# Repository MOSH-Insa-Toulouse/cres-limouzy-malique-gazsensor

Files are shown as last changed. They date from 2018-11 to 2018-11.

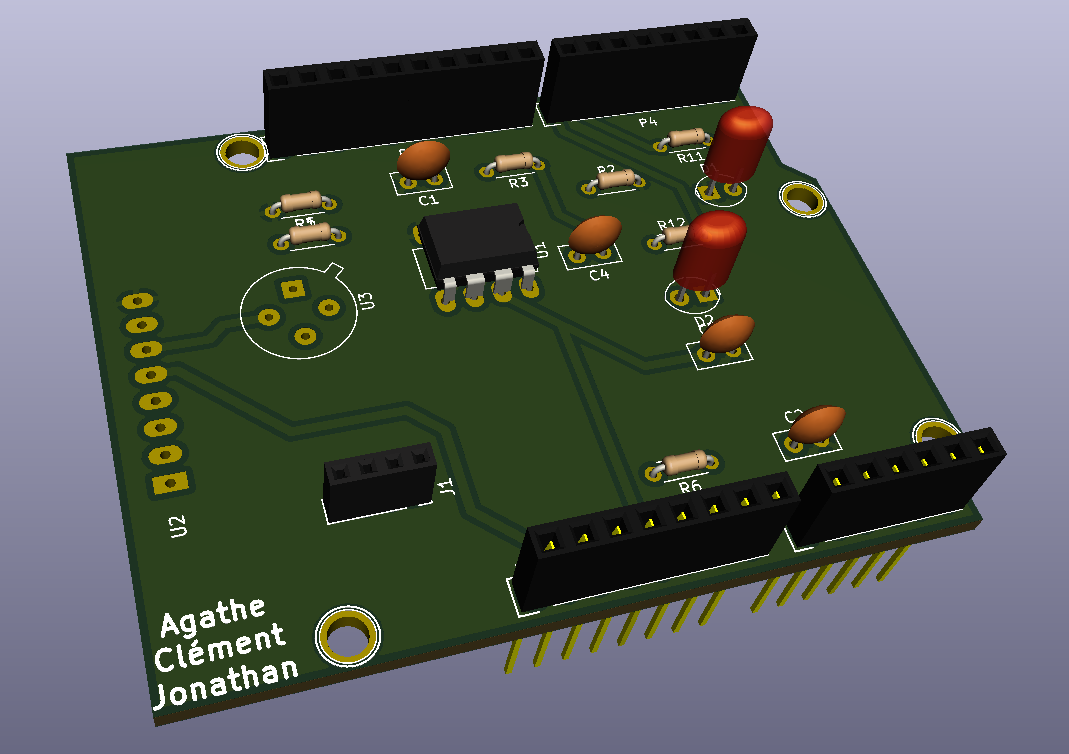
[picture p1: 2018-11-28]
images/3D.PNG

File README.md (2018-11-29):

# Capteur intelligent de gaz monté sur une Arduino Uno
Dans le cadre du cours "Microcontrolleurs et open-source hardware" de 5ème année ISS (Innovative Smart System) à l'INSA de Toulouse, nous avons réalisé un shield Arduino incluant une carte Lora afin de faire transiter les informations issues de divers capteurs sur ledit réseau bas débit. Le projet se décompose en plusieurs parties :
* Création du shield Arduino Uno sous KiCad incluant :
  - la puce Lora RN2483 et son antenne associée
  - le capteur de gaz MQ2 avec connectique GROVE
  - un capteur de gaz "maison" et son étage d'amplification
  - deux LEDs
* Développement d'un programme sous l'IDE Arduino permettant de récupérer les informations issues de divers capteurs branchés sur l'Arduino et les transmettre sur le réseau basse consommation Lora nommé TheThingsNetwork.
* Création d'une interface web affichant les informations issues du capteur de gaz sous la forme d'un graphe, grâce à node-red.

# Prérequis
* Software
	- Arduino IDE avec les bibliothéques SoftwareSerial et TheThingsNetwork
	- Un compte TheThingsNetwork
	- Node-red
* Hardware
	- Un Arduino Uno
	- Un capteur de gaz MQ2 avec connecteur GROVE
	- Deux LEDs
	- Une puce Lora RN2483

# Création d'un shield pour Arduino Uno
Vous pouvez trouver les sources KiCad dans le dossier [ShieldArduinoKiCad](/ShieldArduinoKicad/).
Vous trouverez ci-dessous une vue d'ensemble de la schématique, du routage et du rendu 3D de notre shield.
Schématique du shield Arduino
Routage du shield Arduino - Face 1
Routage du shield Arduino - Face 2
Rendu 3D du shield Arduino

# Développement du software sur Arduino Uno
Le code est distribué dans le dossier [arduino](/arduino/).
Concrétement, il implémente :
* La connexion de la carte Lora au réseau TheThingsNetwork
* La mise en place d'un mode uplink (communication Arduino --> theThingsNetwork via Lora afin d'envoyer les informations issues des capteurs)
* La mise en place d'un mode downlink (communication theThingsNetwork --> Arduino via Lora permettant de commander des LEDs via une interface web). Il est intéressant de noter que la réception d'un message sur l'arduino (message downlink) se fait uniquement après l'envoi d'un message uplink, car la puce RN2483 est un device Lora de classe A. C'est pourquoi il est obligatoire d'envoyer périodiquement une trame (manuellement à l'aide d'un *sendBytes* ou automatiquement à l'aide de la fonction *ttn.poll()*)
* La mise en place de deux LEDs, l'une indiquant un niveau de gaz trop élevé dans la pièce, l'autre permettant de tester le mode downlink

# Développement d'une interface graphique de gestion de données grâce à node-red
Node-red est un outil graphique permettant de lier plusieurs services et APIs ensemble de manière assez facile. Ainsi, nous avons créé une interface permettant d'afficher les informations issues du capteur de gaz sous forme de gauge de danger. De plus, nous avons la possibilité d'allumer, d'éteindre ou de faire clignoter la LED sur notre Arduino, à distance grâce à node-red ou l'interface theThingsNetwork. Vous trouverez ci-dessous l'interface node-red créé pour le projet ainsi que le rendu graphique final.
Interface de programmation de node-red
Rendu graphique final

# FAQ software
## La connexion à TheThingsNetwork ne fonctionne pas
* Réinitialiser l'Arduino à l'aide du bouton RESET, ainsi que la carte Lora en branchant la pin RST du RN2483 sur la masse de l'arduino pendant quelques secondes
* Vérifier qu'une gateway Lora est bien présente aux alentours et que le signal est suffisamment fort pour permettre la connexion

## La connexion de node-red à TheThingsNetwork est impossible
* Vérifier que votre routeur internet ne bloque pas la connexion

## Le mode uplink ne fonctionne pas
* Vérifier que la connexion avec TheThingsNetwork est bien réalisée à l'aide de la console série Arduino
* Cliquer sur "RESET FRAME COUNTERS" sur la page de votre device sur TheThingsNetwork

## Le mode downlink ne fonctionne pas
* Vérifier que la connexion avec TheThingsNetwork est bien réalisée à l'aide de la console série Arduino
* Vérifier que votre code envoie périodiquement des trames Lora afin de permettre les messages downlink

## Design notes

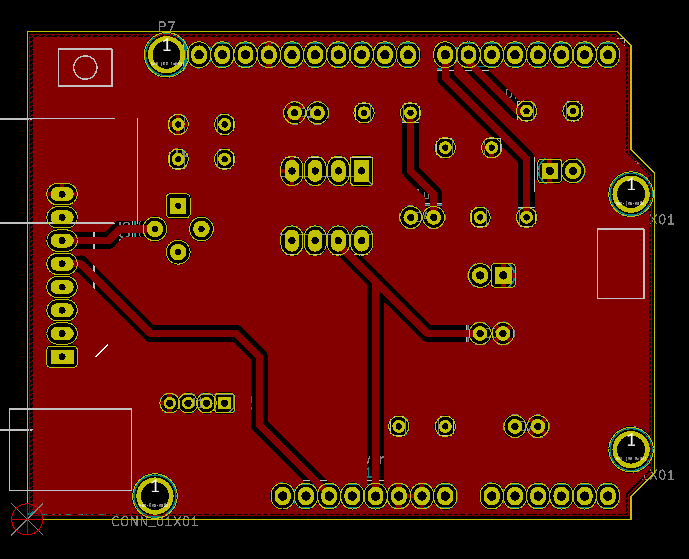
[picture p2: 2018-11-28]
images/routageB.PNG

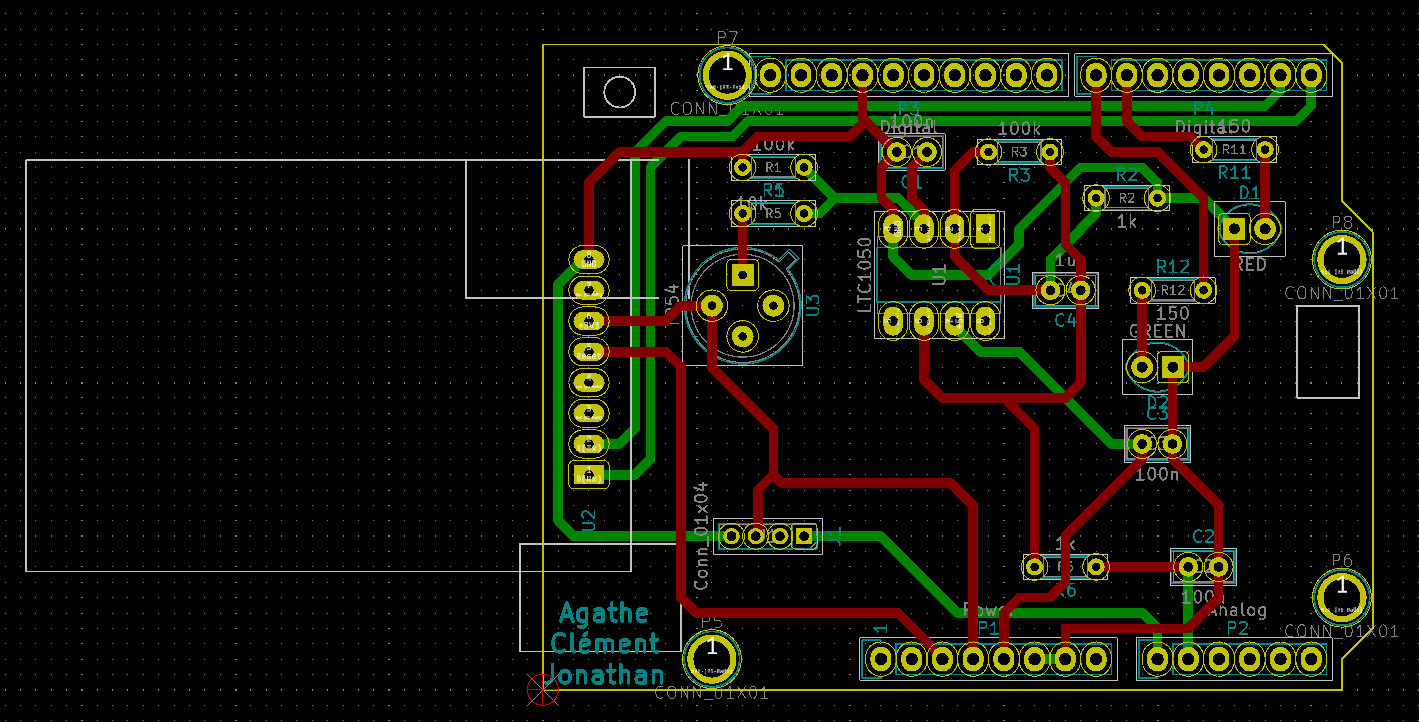
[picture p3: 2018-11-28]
images/routage.PNG

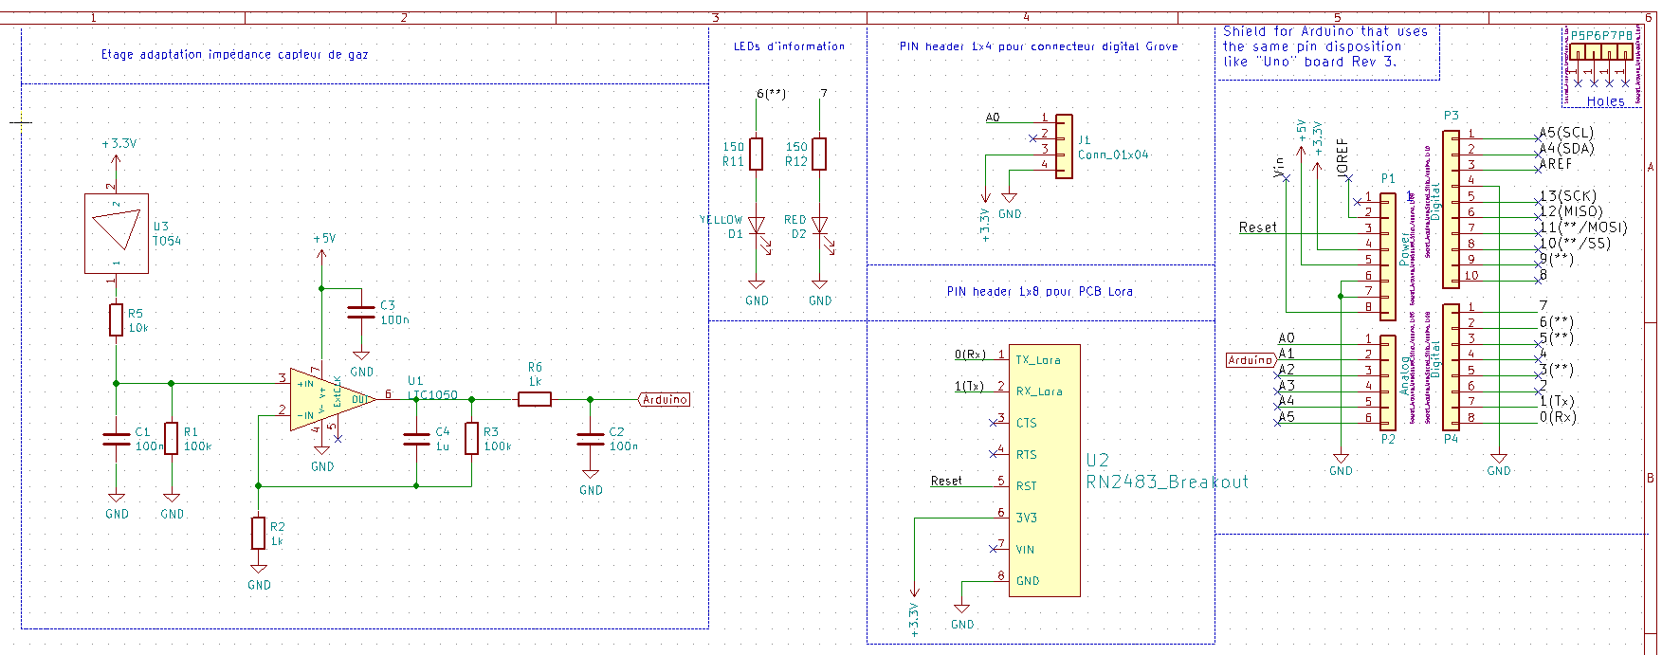
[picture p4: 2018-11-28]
images/schematique.PNG

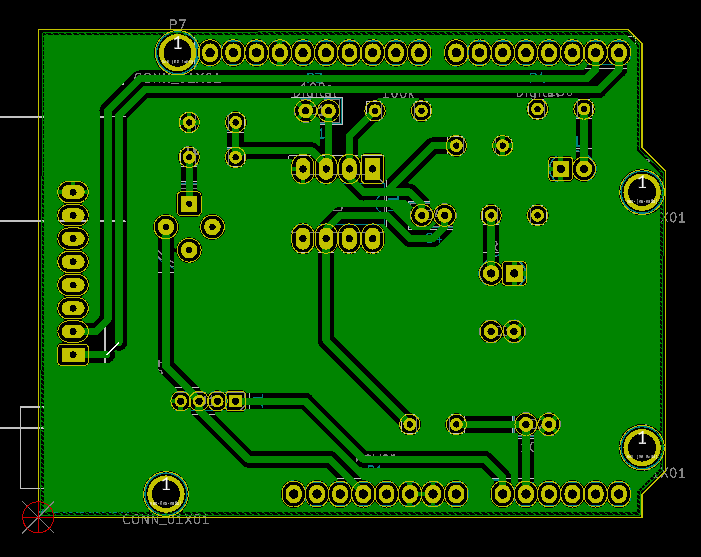
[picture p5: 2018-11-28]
images/routageA.PNG

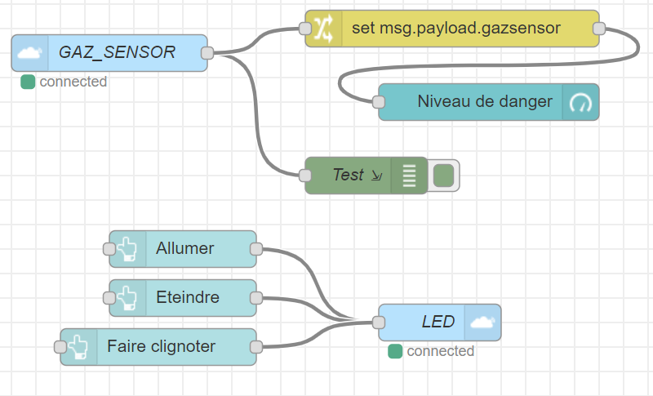
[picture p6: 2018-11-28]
images/node-red-principal.PNG

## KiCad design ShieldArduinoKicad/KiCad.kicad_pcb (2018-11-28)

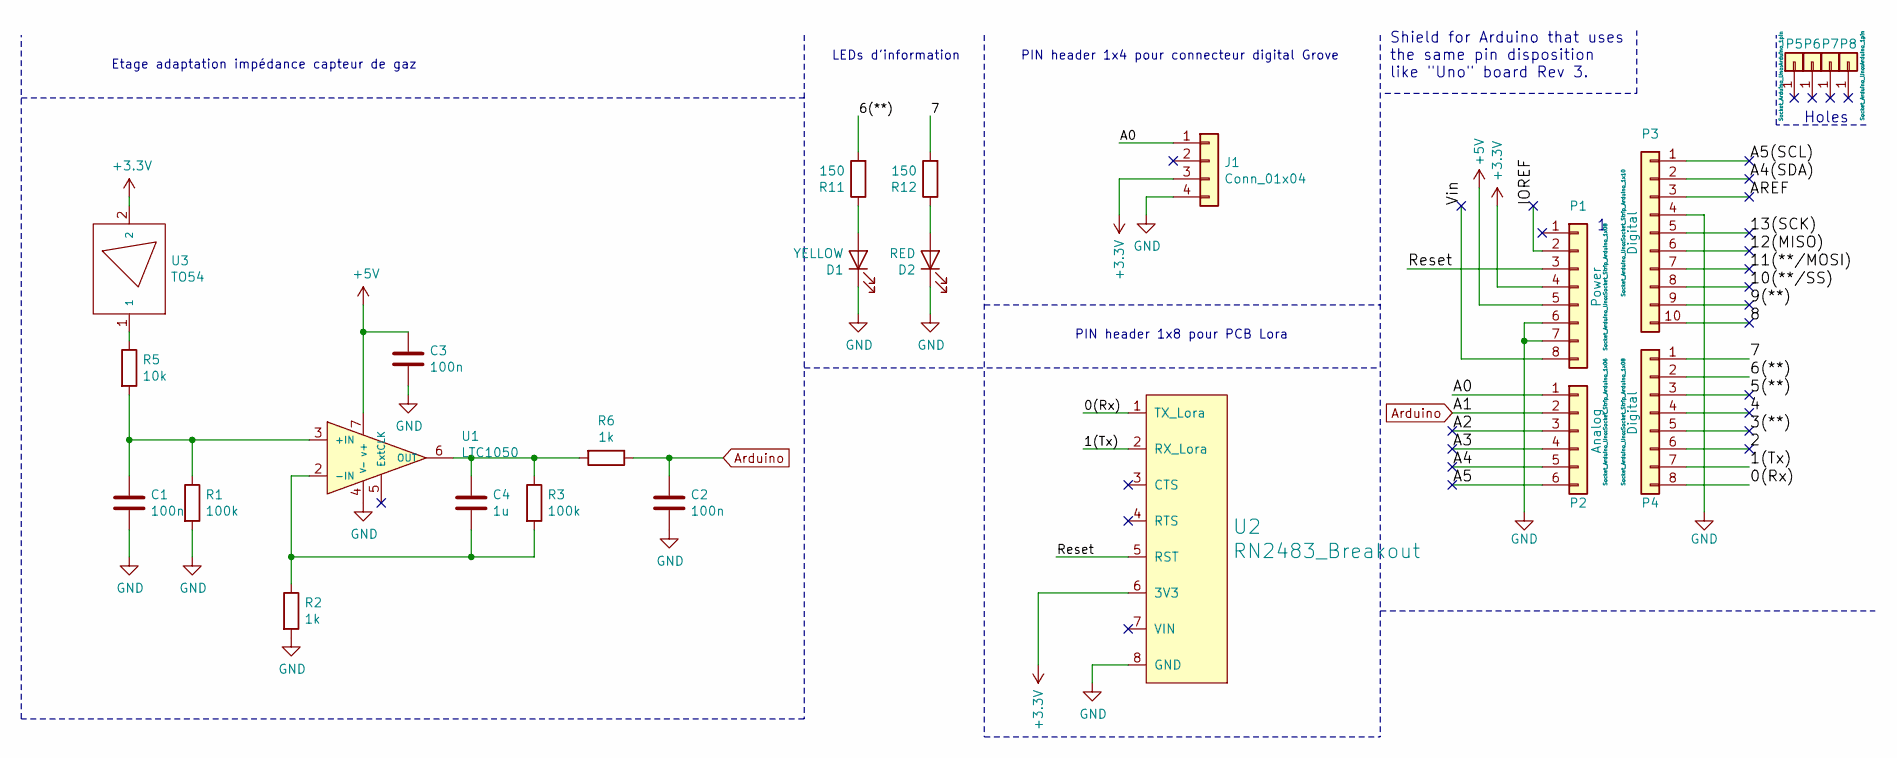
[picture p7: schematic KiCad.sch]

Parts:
C1, C2, C3: 100n; C_Disc_D5.0mm_W2.5mm_P2.50mm
C4: 1u; C_Disc_D5.0mm_W2.5mm_P2.50mm
D1: YELLOW; LED_Oval_W5.2mm_H3.8mm
D2: RED; LED_Oval_W5.2mm_H3.8mm
J1: Conn_01x04; JST_PH_B4B-PH-K_1x04_P2.00mm_Vertical
P1: Power; Socket_Strip_Arduino_1x08
P2: Analog; Socket_Strip_Arduino_1x06
P3: Digital; Socket_Strip_Arduino_1x10
P4: Digital; Socket_Strip_Arduino_1x08
P5, P6, P7, P8: CONN_01X01; Arduino_1pin
R1, R3: 100k; R_Axial_DIN0204_L3.6mm_D1.6mm_P5.08mm_Horizontal
R2, R6: 1k; R_Axial_DIN0204_L3.6mm_D1.6mm_P5.08mm_Horizontal
R5: 10k; R_Axial_DIN0204_L3.6mm_D1.6mm_P5.08mm_Horizontal
R11, R12: 150; R_Axial_DIN0204_L3.6mm_D1.6mm_P5.08mm_Horizontal
U1: LTC1050; DIP-8_W7.62mm_LongPads
U2: RN2483_Breakout; Module_RN2483_Breakout
U3: TO54

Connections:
+3V3: J1.3, P1.4, U2.6 (3V3), U3.2
+5V: C3.1, P1.5, U1.7 (v+)
/0(Rx): P4.8, U2.1 (TX_Lora)
/1(Tx): P4.7, U2.2 (RX_Lora)
/2: P4.6
/3(**): P4.5
/4: P4.4
/5(**): P4.3
/6(**): P4.2, R11.2
/7: P4.1, R12.2
/8: P3.10
/9(**): P3.9
/10(**/SS): P3.8
/11(**/MOSI): P3.7
/12(MISO): P3.6
/13(SCK): P3.5
/A0: J1.1, P2.1
/A2: P2.3
/A3: P2.4
/A4: P2.5
/A4(SDA): P3.2
/A5: P2.6
/A5(SCL): P3.1
/AREF: P3.3
/IOREF: P1.2
/Reset: P1.3, U2.5 (RST)
/Vin: P1.8
Arduino: C2.1, P2.2, R6.1
GND: C1.2, C2.2, C3.2, D1.1 (K), D2.1 (K), J1.4, P1.6, P1.7, P3.4, R1.2, R2.2, U1.4 (V-), U2.8 (GND)
unnamed: C1.1, R1.1, R5.2, U1.3 (+IN)
unnamed: C4.1, R3.1, R6.2, U1.6 (OUT)
unnamed: C4.2, R2.1, R3.2, U1.2 (-IN)
unnamed: D1.2 (A), R11.1
unnamed: D2.2 (A), R12.1
unnamed: R5.1, U3.1

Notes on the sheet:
Holes
Shield for Arduino that uses the same pin disposition like "Uno" board Rev 3.
PIN header 1x4 pour connecteur digital Grove
PIN header 1x8 pour PCB Lora
LEDs d'information
Etage adaptation impédance capteur de gaz

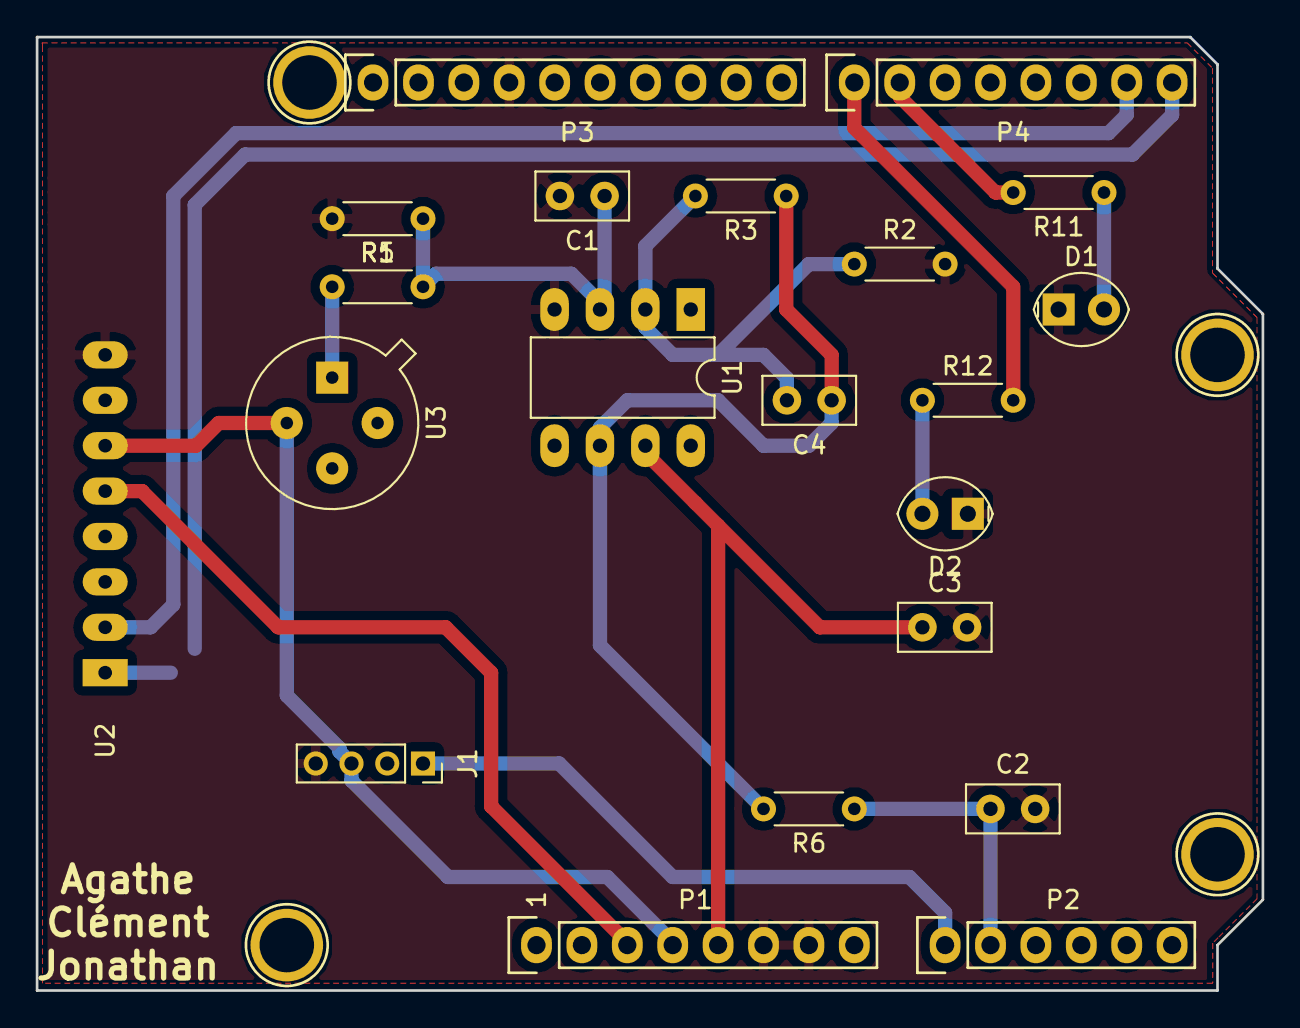
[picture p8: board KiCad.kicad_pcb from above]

Board: 2 copper layers, 68.6 x 53.3 mm, 25 parts (0 on the bottom side), 16 nets.

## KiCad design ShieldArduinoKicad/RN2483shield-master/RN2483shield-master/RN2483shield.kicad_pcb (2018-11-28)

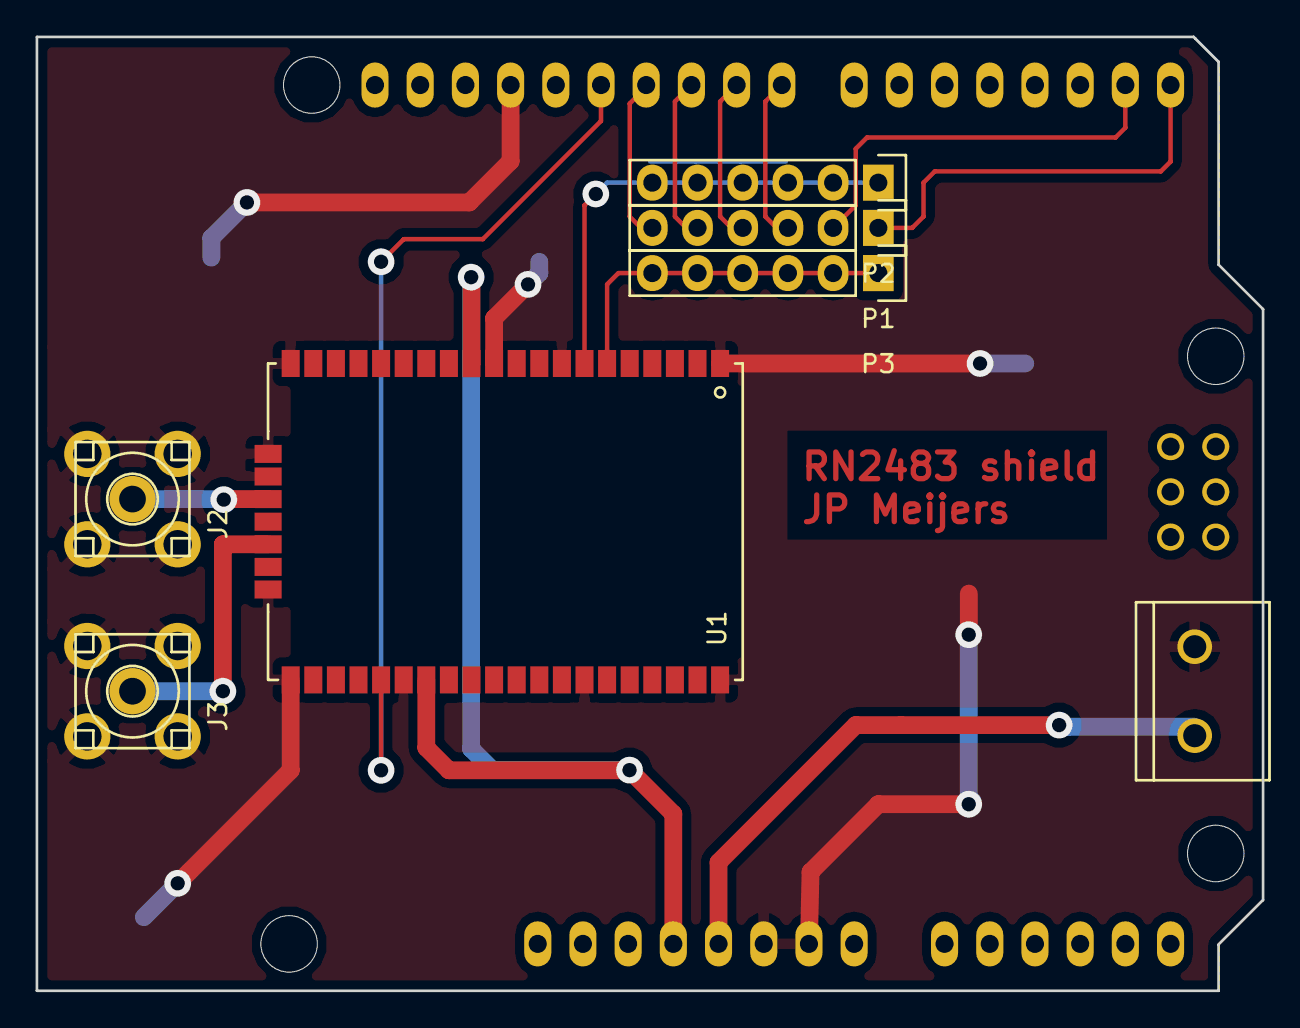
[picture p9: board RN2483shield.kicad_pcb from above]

Board: 2 copper layers, 68.9 x 53.6 mm, 8 parts (0 on the bottom side), 14 nets.

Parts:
J1: SCREW_TERMINAL; SCREWTERMINAL-5MM-2
J2, J3: SMA; SMA_BOARD_UPRIGHT
P1, P2, P3: CONN_01X06; Socket_Strip_Straight_1x06
SHIELD1: ARDUINO_SHIELD
U1: RN2483

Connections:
3.3VOLT: SHIELD1.3V3, U1.12, U1.34
/AD_P8: P1.3, SHIELD1.8
/AD_P9: P1.4, SHIELD1.9
/AD_P10: P1.5, SHIELD1.10
/AD_P11: P1.6, SHIELD1.11
/HW_RX: P1.1, SHIELD1.0
/HW_TX: P1.2, SHIELD1.1
BATTERY: J1.2, SHIELD1.5V
GND: J1.1, J2.2, J2.3, J2.4, J2.5, J3.2, J3.3, J3.4, J3.5, SHIELD1.GND1, SHIELD1.GND2, SHIELD1.GND3, U1.1, U1.8, U1.11, U1.20, U1.21, U1.22, U1.24, U1.26, U1.27, U1.28, U1.33, U1.41, U1.47
unnamed: J2.1, U1.23
unnamed: J3.1, U1.25
RN_RESET: SHIELD1.12, U1.32
UART_ARDUINO_TO_RADIO: P2.1, P2.2, P2.3, P2.4, P2.5, P2.6, U1.7
UART_RADIO_TO_ARDUINO: P3.1, P3.2, P3.3, P3.4, P3.5, P3.6, U1.6

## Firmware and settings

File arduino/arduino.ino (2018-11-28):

#include <SoftwareSerial.h>
#include <TheThingsNetwork.h>

// Define PINS
const byte ledPinYellow = 6;
const byte ledPinRed = 7;
const byte gasAnalogPin = A0;
const byte RXPin = 10;
const byte TXPin = 11;
#define ETEINDRE_LED 0
#define ALLUMER_LED 1
#define CLIGNOTER_LED 2
byte commande;

// Set your DevAddr, NwkSKey, AppSKey and the frequency plan
const char *devAddr = "26011072";
const char *nwkSKey = "B5882EE1202009675E917971350860FF";
const char *appSKey = "4C4E18A868F7BC42C9CC9ACD894F2921";
#define freqPlan TTN_FP_EU868

// Define PINS for connection between the Arduino and the Lora Shield + for debug
SoftwareSerial loraSerial(RXPin, TXPin); // RX, TX
#define debugSerial Serial
TheThingsNetwork ttn(loraSerial, debugSerial, freqPlan);

void setup()
{
  // Set the baud rate
  loraSerial.begin(57600);
  debugSerial.begin(9600);

  // Set the pinMode
  pinMode(gasAnalogPin, INPUT);
  pinMode(ledPinYellow, OUTPUT);
  pinMode(ledPinRed, OUTPUT);

  // Wait a maximum of 10s for Serial Monitor
  while (!debugSerial && millis() < 10000);

  // Set callback for incoming messages
  ttn.onMessage(message);

  debugSerial.println("-- PERSONALIZE");
  ttn.personalize(devAddr, nwkSKey, appSKey);

  debugSerial.println("-- STATUS");
  ttn.showStatus();

  commande = ETEINDRE_LED;
}

void loop()
{
  // Definition of variables
  float sensor_volt;
  float sensorValue;
  int valEntiere;
  int valDecimale;
  
  debugSerial.println("-- LOOP");
  debugSerial.print("-- GAS SENSOR : ");

  sensorValue = analogRead(gasAnalogPin);
  sensor_volt = sensorValue/1024*5.0;
  debugSerial.println(sensor_volt);
  
  // New format to send the data to TTN
  // If sensor_volt equals 2.45, it will become 2 variables : valEntiere = 2 and valDecimale = 45
  valEntiere = (int) sensor_volt;
  valDecimale = (sensor_volt - valEntiere)*100;
  debugSerial.print("Partie entiere : ");
  debugSerial.print(valEntiere);
  debugSerial.print("-- Partie decimale : ");
  debugSerial.print(valDecimale);

  // Prepare payload of 1 byte to indicate LED status
  byte payload[2];
  payload[0] = valEntiere;
  payload[1] = valDecimale;

  // send the frame
  ttn.sendBytes(payload, sizeof(payload));

  // Setup an alarm if the sensor detect a high-voltage gas
  // It will light on the red light if there is a danger
  if(sensor_volt > 0.75) {
    digitalWrite(ledPinRed, HIGH);
  } else {
    digitalWrite(ledPinRed, LOW);
  }

  // These functions can be launch by rednode wirelessly OR by the console on theThingsNetwork
  if(commande == 1) {
    debugSerial.println("LED: on");
    digitalWrite(ledPinYellow, HIGH);
  } else if(commande == 0) {
    debugSerial.println("LED: off");
    digitalWrite(ledPinYellow, LOW);
  } else if(commande == 2) {
      debugSerial.println("LED: blink");
      if(digitalRead(ledPinYellow) == 1) {
        digitalWrite(ledPinYellow, LOW);
      } else {
        digitalWrite(ledPinYellow, HIGH);
      }
  }

  // Send single byte to poll for incoming messages. You need to activate it if you want downlink message without using sendBytes() function
  //ttn.poll();

  // Define the periodicity of your sending data function
  delay(4000);
}

// Handle message from node-red or theThingsNetwork
void message(const byte *payload, size_t length, port_t port)
{
  debugSerial.println("-- MESSAGE");

  // Only handle messages of a single byte
  if (length != 1)
  {
    return;
  }

  commande = payload[0];
}
